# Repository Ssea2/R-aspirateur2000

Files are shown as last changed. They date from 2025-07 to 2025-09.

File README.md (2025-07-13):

# R-aspirateur2000

## Objectif

L'objectif est de faire un robot fonctionnel et fiable pour la Coupe de France de robotique 2026

## arborescence des fichiers

R-aspirateur2000
    - BaseRoulante: le code qui permet de déplacer le robot en prennant compte des colisions 
    - doc: comme suggère le nom
    - modele_3D_2D: comme suggère le nom

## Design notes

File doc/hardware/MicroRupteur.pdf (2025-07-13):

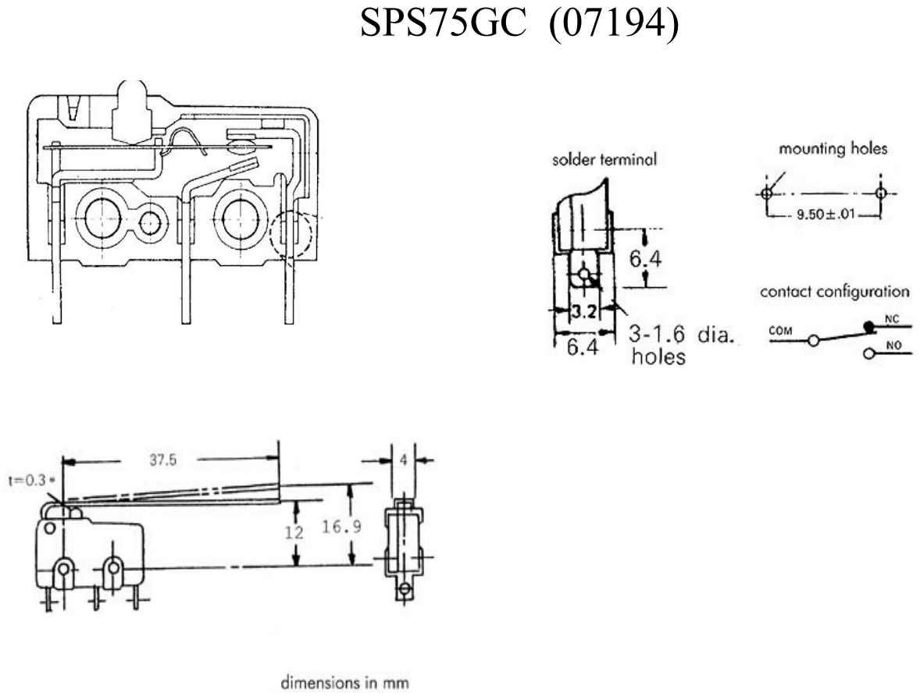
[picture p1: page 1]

SPS75GC (07194)

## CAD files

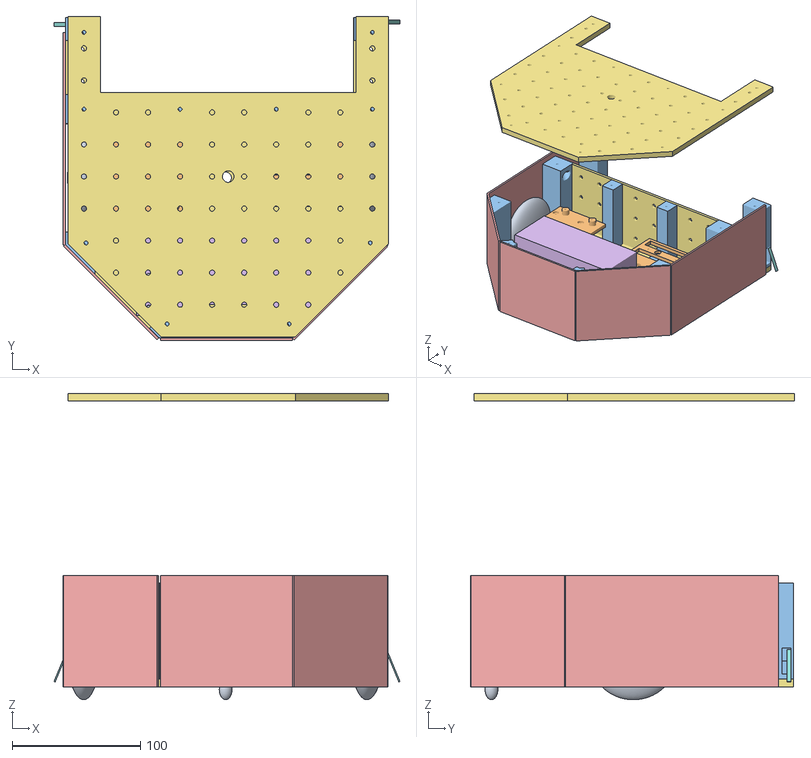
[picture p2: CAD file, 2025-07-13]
modele_3D_2D/tinker.obj
269.9 x 253.0 x 239.0

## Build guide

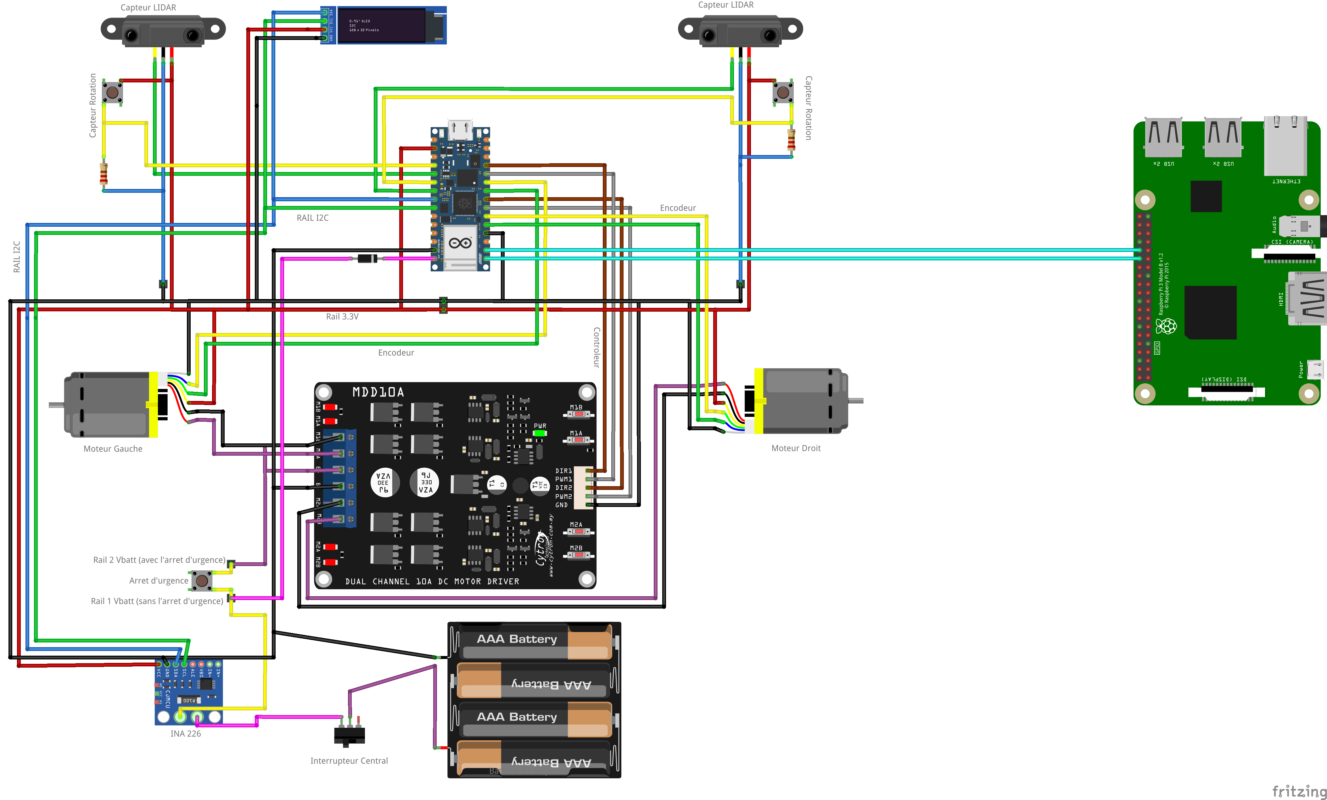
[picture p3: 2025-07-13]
doc/Cablage/wiring_bb.png

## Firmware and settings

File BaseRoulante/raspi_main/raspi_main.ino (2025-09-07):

#include <CytronMotorDriver.h>

#include "raspi_config.h"


static unsigned long lastMs = 0;
const unsigned long intervalMs = 20;


const int enca[] = {L_EncoderA, R_EncoderA};
const int encb[] = {L_EncoderB, R_EncoderB};
const int inA[] = {L_MotorA, R_MotorA};
const int inB[] = {L_MotorB, R_MotorB};

volatile int posi[] = {0,0};


float wheel_perimeter = PI*DIAM_WHEEL;
int speed_left;
int speed_right;
int speed = 60;
int dirL;
int dirR;
int target;
int dsec = 100; // mm
int Lldist;
int Rldist;
long cL;
long cR;
int stoptype;
int (*pulse2value)(int);
float restvalue;
float actionfaite[] = {0,0,0};

float move[] = {90,500}; // roatation en degrée et translation en mm


CytronMD motor_Left( PWM_PWM, inA[0], inB[0]);
CytronMD motor_Right(PWM_PWM, inA[1], inB[1]);

template <int j>
void readEncoder(){
  int b = digitalRead(encb[j]);
  if(b > 0){
    posi[j]--;
  }
  else{
    posi[j]++;
  }
}

int dist2encodeurvalue(float distmm){
  int nb_pulsation;
  nb_pulsation = (distmm/wheel_perimeter)*nbPPR;
  return nb_pulsation;
}


float angle2encodervalue(float angle){
  float P_arc;
  int nbPulseAngle;
  // convertir un angle en distance
  P_arc= (PI*D_BETWEEN_WHEEL*angle)/360;
  nbPulseAngle = dist2encodeurvalue(P_arc);
  return nbPulseAngle;
}

int encodeurvalue2dist(int pulse){
  float dist;
  dist = (pulse*wheel_perimeter)/nbPPR;
  return dist;
}
float encodervalue2angle(int pulse){
  float angle;
  float dist = encodeurvalue2dist(pulse);
  angle = (dist*360)/(PI*D_BETWEEN_WHEEL);
  return angle;
}


float getspeed(long pos, float dtime){
  float Covers = pos/dtime;
  float rpm = (Covers/nbPPR)*60.0;
  //float mps = (rpm*PI*(DIAM_WHEEL/1000))/60;
  return Covers;
}


// Get distance from pololu sensor
int getDistance(int sensorPin) {
  int16_t t ;
  int flag = 0;
  while (flag == 0) {
    t = pulseIn(sensorPin, HIGH);
    if (t == 0) {
    } else if (t > 1850) {
      return 500;      
    } else {
      int16_t d = (t - 1000) * 3 / 4;
      if (d < 0) { d = 0; }
      return d;
    }
  }
}

// get Status from switch
int getStop(int sensorPin) {
  int val = analogRead(sensorPin);
  if (val <= 512) { return 0; } 
  else            { return 1; }
}

bool iscollision_front(float dist_secu){
  int Lldist = getDistance(L_Distance);
  int Rldist = getDistance(R_Distance);
  if (Lldist < dist_secu || Rldist < dist_secu){
    return true;
  }
  else {
    return false;
  }
}

bool iscollision_LR(){
  if (getStop(L_Collision) || getStop(R_Collision)){
    return true;
  }
  else {
    return false;
  }
}


void setup() {
  Serial.begin(9600);

  pinMode(L_Collision , INPUT);
  pinMode(L_Distance  , INPUT);

  pinMode(R_Collision , INPUT);
  pinMode(R_Distance  , INPUT);


  for (int i=0; i<NBMOTOR; i++){
    pinMode(enca[i] , INPUT);
    pinMode(encb[i] , INPUT);
    pinMode(inA[i]  , OUTPUT);
    pinMode(inB[i]  , OUTPUT);
  /*pinMode(L_EncoderA  , INPUT);
  pinMode(L_EncoderB  , INPUT);
  pinMode(L_MotorB    , OUTPUT);
  pinMode(L_MotorA    , OUTPUT);

  pinMode(R_EncoderA  , INPUT);
  pinMode(R_EncoderB  , INPUT);
  pinMode(R_MotorB    , OUTPUT);
  pinMode(R_MotorA    , OUTPUT);*/
  }
    // Initialize Encoder
  attachInterrupt(digitalPinToInterrupt(L_EncoderA), readEncoder<0>, RISING);
  attachInterrupt(digitalPinToInterrupt(R_EncoderA), readEncoder<1>, RISING);

}

void loop(){  
  // on itere pour la rotation puis la translation
  for (int i=0; i<2; i++){
    int action = move[i];
    if (action !=0){ // si l'action vaut 0 on la skip 
      if (i==0){
        // la direction des roues dépend de l'angle, positif on tourne dans le sans anti-horraire et vice versa
        if (action > 0){
          dirL=-1;
          dirR=1;
        }
        else {
          dirL=1;
          dirR=-1;
        }
        // on transforme l'angle en nb de pulsation
        pulse2value=encodeurvalue2dist;
        target = angle2encodervalue(action);
      }
      else {
        dirL=1;
        dirR=1;
        // on transforme la distance en nombre de pulsation
        target = dist2encodeurvalue(action);
        pulse2value=encodeurvalue2dist;
      }

      // pulsation a 0 avant chaque mouvement
      noInterrupts();
      posi[0] = 0;
      posi[1] = 0;
      interrupts();
      // on set la vitesse 
      speed_left = dirL*speed;
      speed_right = dirR*(COEFR2L*speed + BIASR2L);
      
      while (true){
        // recuperation des comptes de pulsation
        noInterrupts();
        cL = posi[0];
        cR = posi[1];
        interrupts();

        // test des condition qui meme a l'arret de la base roulante 
        if (fabs(cR) >= target) { // action entierement faite
          stoptype=0;
          break;  // on sort de la boucle
        }
        else if (iscollision_front(dsec)){ // distance de securite a l'avant
          stoptype=1;
          break;
        }
        else if (iscollision_LR()){ // les sswitch sur les coté du robot
          stoptype=2;
          break;
        }
        else {
          motor_Left.setSpeed(speed_left); motor_Right.setSpeed(speed_right);
        }
        // on sauvegarde la distance/angle parcouru avant l'interuption
        actionfaite[i]=pulse2value(cL);
        // même chose mais avec le type d'interuption 0=normal, 1=collision avant, 2=collision cote
        actionfaite[2]=stoptype;
        
        
        
      }
      motor_Left.setSpeed(0); motor_Right.setSpeed(0);
  
    }
    else {
      motor_Left.setSpeed(0); motor_Right.setSpeed(0);
    }
  }
  // on envoie les infos des actoin effectué en utilisant le port série
  for (int i=0; i<3;i++){
    Serial.print(actionfaite[i]);
    Serial.print(",");
  }
  Serial.println();

}

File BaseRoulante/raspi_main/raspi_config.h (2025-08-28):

#ifndef CONFIG_H
#define CONFIG_H

// parametre du robot
#define COEFR2L 0.96 //0.96
#define BIASR2L 1

#define D_BETWEEN_WHEEL 222 //mm 
#define CENTER2WHEEL 111 //mm
#define DIAM_WHEEL  70.0 //mm
#define nbPPR 341.2 // le nombre de pulsation des encodeurs par tour apres le réducteur 34:1

#define NBMOTOR 2

// ---------------PIN----------------

// Pin motors Left
#define L_EncoderA 6
#define L_EncoderB 7
#define L_MotorB 8
#define L_MotorA 9

// Pin motors Right
#define R_EncoderA 2
#define R_EncoderB 3
#define R_MotorB 4
#define R_MotorA 5


// Collision and Distance
// Left Sensor
#define L_Collision A0
#define L_Distance A1

// Right Sensor
#define R_Collision A2
#define R_Distance A3


#endif 

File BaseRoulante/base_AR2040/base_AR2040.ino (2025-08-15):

#include <CytronMotorDriver.h>

// Pin motors Left
#define L_EncoderA 6
#define L_EncoderB 7
#define L_MotorB 8
#define L_MotorA 9

// Pin motors Right
#define R_EncoderA 2
#define R_EncoderB 3
#define R_MotorB 4
#define R_MotorA 5

CytronMD motor_Left( PWM_PWM, L_MotorA, L_MotorB);
// vitesse du moteur droit = vitesse moteur gauche -9
// 128 = 655
//  x  = 610
CytronMD motor_Right(PWM_PWM, R_MotorA, R_MotorB);

long countL_nb = 0;
long countR_nb = 0;

int il = 0;
int ir = 0;

// parametre du robot
#define COEFR2L 0.96
#define BIASR2L 0

void countL() { countL_nb += 1; }
void countR() { countR_nb += 1; }

void setup() {
  Serial.begin(9600);

  pinMode(L_EncoderA  , INPUT);
  pinMode(L_EncoderB  , INPUT);
  pinMode(L_MotorB    , OUTPUT);
  pinMode(L_MotorA    , OUTPUT);

  pinMode(R_EncoderA  , INPUT);
  pinMode(R_EncoderB  , INPUT);
  pinMode(R_MotorB    , OUTPUT);
  pinMode(R_MotorA    , OUTPUT);

    // Initialize Encoder
  attachInterrupt(digitalPinToInterrupt(L_EncoderA), countL, RISING);
  attachInterrupt(digitalPinToInterrupt(R_EncoderA), countR, RISING);
}

void loop(){
  delay(10000);
  countL_nb = 0; countR_nb = 0;
  for (float i=25; i<128; i++){
    il = i;
    ir = (COEFR2L * i) + BIASR2L;
    motor_Left.setSpeed(il); motor_Right.setSpeed(ir);
    delay(10);
    Serial.print(i);
    Serial.print(",");
    Serial.print(countL_nb);
    Serial.print(",");
    Serial.print(countR_nb);
    Serial.print("\n");
  }
  for (float i=128; i>25; i--){
    il = i;
    ir = (COEFR2L * i) + BIASR2L;
    motor_Left.setSpeed(il); motor_Right.setSpeed(ir);
    delay(10);
    Serial.print(i);
    Serial.print(",");
    Serial.print(countL_nb);
    Serial.print(",");
    Serial.print(countR_nb);
    Serial.print("\n");
  }
  
  motor_Left.setSpeed(0); motor_Right.setSpeed(0);
  

  
}

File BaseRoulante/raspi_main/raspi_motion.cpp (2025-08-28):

/*#include <CytronMotorDriver.h>
#include <Arduino.h>

#include "raspi_config.h"
#include "raspi_motion.h"

int speed_left;
int speed_right;
float countL_nb;
float countR_nb;

float dist_between_wheel = 22.2;
float diameter_wheel = 70.0;

float wheel_perimeter = 2*PI*diameter_wheel; 


CytronMD motor_Left( PWM_PWM, L_MotorA, L_MotorB);
CytronMD motor_Right(PWM_PWM, R_MotorA, R_MotorB);

void countL() { countL_nb += 1; }
void countR() { countR_nb += 1; }


int forward(int speed){
  countL_nb=0;
  countR_nb=0;
  speed_left = speed;
  speed_right = (COEFR2L * speed) -2 ;
  motor_Left.setSpeed(speed_left); motor_Right.setSpeed(speed_right);
  for (int i; i< 1000; i++){
  //Serial.print(N);
  //Serial.print(",");
  //Serial.print(speed);
  //Serial.print(",");
  //Serial.print(speed_left);
  //Serial.print(",");
  //Serial.print(speed_right);
  //Serial.print(",");
    Serial.println(countL_nb);
    //Serial.print(",");
    //Serial.print(countR_nb);
  //Serial.print("\n");
    delay(1);
  }
  return 0;

  int target = 600;

  // PID constants
  float kp = 0.1;
  float kd = 0.025;
  float ki = 0.0;

  // time difference
  long currT = micros();
  float deltaT = ((float) (currT - prevT))/( 1.0e6 );
  prevT = currT;

  int pos = 0; 
  pos = posi;

  // error
  int e = pos - target;

  // derivative
  float dedt = (e-eprev)/(deltaT);

  // integral
  eintegral = eintegral + e*deltaT;

  // control signal
  float u = kp*e + kd*dedt + ki*eintegral;

  // motor power
  float pwr = fabs(u);
  if( pwr > 128 ){
    pwr = 128;
  }
  if( pwr < 25 ){
    pwr = 25;
  }

  // motor direction
  int dir = 1;
  if(u<0){
    dir = -1;
  }

  // signal the motor
  int speed = dir*pwr;
  motor_Left.setSpeed(speed);


  // store previous error
  eprev = e;

  Serial.print(target);
  Serial.print(" ");
  Serial.print(pos);
  Serial.print(" ");
  Serial.print(speed);
  Serial.println();
}*/


/*

void rotate(float angle, int speed=50){
  int dirL=1;
  int dirR=1;

  if (angle >0){
    dirL=-1;
    dirR=1;
  }
  else if (angle < 0){
    dirL=1;
    dirR=-1;
  }
  int target = dirL*angle2encodervalue(angle);
  speed_left = speed*dirL;
  speed_right = (COEFR2L * speed)*dirR;
  motor_Left.setSpeed(speed_left); motor_Right.setSpeed(speed_right);
  while (dirL*posi < target){
    int e = dirL*target - dirL*posi;
    Serial.print(e);
    Serial.print("||");
    Serial.print(posi);
    Serial.println();
  }
  delay(3000);
  motor_Left.setSpeed(0); motor_Right.setSpeed(0);
  }

  
float wheel_perimeter = PI*DIAM_WHEEL; 



void ForBackWard(float dist, int speed=50){
  int dir;
  if (dist > 0){
    dir = 1;
  }
  else{
    dir=-1;
  }
  int target = dir*dist2encodeurvalue(dist);
  Serial.println(target);
  delay(3000);
  speed_left = speed*dir;
  speed_right = (COEFR2L * speed)*dir;
  motor_Left.setSpeed(speed_left); motor_Right.setSpeed(speed_right);
  while (dir*posi < target){
    int e = dir*target - dir*posi;
    Serial.print(e);
    Serial.print("||");
    Serial.print(posi);
    Serial.println();
  }
  motor_Left.setSpeed(0); motor_Right.setSpeed(0);
  
//delay(1000);
  /*for (int i=0; i<3000;i++){
    Serial.println();
    Serial.print(posi[0]);
    Serial.print(" || ");
    Serial.print(posi[1]);
    Serial.println();
  }
  unsigned long now = millis();
  if (now - lastMs >= intervalMs) {

    noInterrupts();
    long cA = posi[0]; posi[0] = 0;
    long cB = posi[1]; posi[1] = 0;
    interrupts();

    float dt = (now - lastMs) / 1000.0; // en secondes
    float rpmL = getspeed(cA, dt);
    float rpmR = -1*getspeed(cB, dt);
    Serial.print(lm);
    Serial.print(",");
    Serial.print(rpmL);
    Serial.print(",");
    Serial.print(-1*rpmR);
    Serial.println();


    lastMs = now;
    lm++;
}*/

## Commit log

2025-07-13 dépot des 1er fichier
    [tinker.obj, wiring.fzz]
2025-08-15 restructuration du code & ajout de fonction pour avancer reculer et tourner
    [pyvenv.cfg, tinker.obj, value.csv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]
2025-08-23 feat: mouvement linéaire fonctionel prend une distance en parametre. les rotations ne marche pas très bien manque une régulation
    [pyvenv.cfg, value.csv]
2025-08-28 feat: rotation puis translation du robot suite a un ordre de la forme (angle, distance)
2025-09-07 feat: renvoie des distance/angle parcouru par le robbot avant intéruption
    [pyvenv.cfg, value.csv]
